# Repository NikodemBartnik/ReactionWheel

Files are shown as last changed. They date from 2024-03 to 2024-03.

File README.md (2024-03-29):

# Reaction Wheel by Nikodem Bartnik
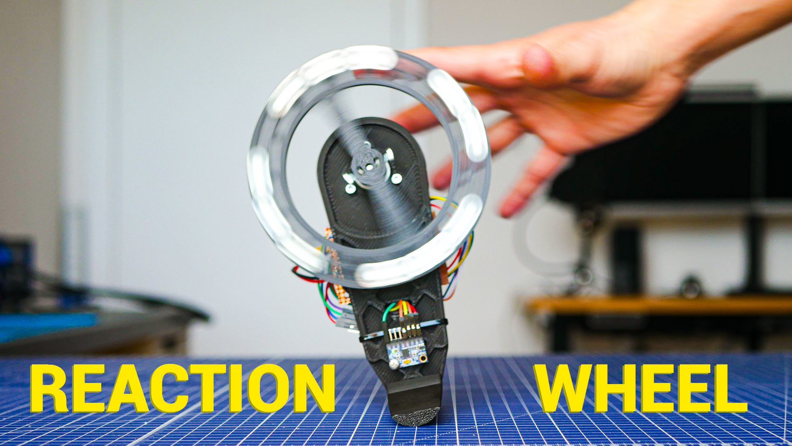
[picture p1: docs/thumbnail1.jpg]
DIY Reaction Wheel by Nikodem Bartnik

At some point in the past, I made a mistake. I embarked on a reaction wheel project, thinking it would be straightforward after watching a few YouTube videos. It turned out to be far from simple. It took me around 4 or 5 attempts to finally complete the project, during which I made numerous mistakes and learned valuable lessons.

Having previously built my own Arduino-based drone, I've come to realize that stability isn't my forte. However, that hasn't dampened my enthusiasm for future projects.

## Overview
The project was initiated in 2019 but was frequently interrupted by other endeavors. There were times when I felt frustrated after days of working on it without making any progress. With this candid introduction, I must caution you that this project isn't the easiest for beginners.

## Parts
Most parts are simply 3D printed. You will also need:
* [Arduino Nano](https://amzn.to/49duqW5)- A small and inexpensive option that can be easily soldered to a protoboard. Opting for a smaller size facilitates stabilizing smaller masses on the reaction wheel.
* [Nidec24H brushless motor](https://s.click.aliexpress.com/e/_DFDXhbX) - This motor is popular for building reaction wheels due to its high torque and integrated driver.
* [MPU6050](https://amzn.to/3Tzr75X) - An affordable and widely used accelerometer and gyroscope. While its data may not be pristine, it gets the job done. Consider upgrading to a higher-quality alternative if necessary, albeit at a higher cost.
* [Protoboard](https://amzn.to/4cDcS8C) - Any size will suffice, and you can always trim it down to fit. It's handy for creating a compact board with all the necessary components attached to the back of your reaction wheel.
* [Bluetooth module](https://amzn.to/3IZgXGY) -  Essential for fine-tuning the PID algorithm.
* Other components: Screws, nuts, LiPo battery, cables.

## Video about the project
Reaction Wheel Video (https://www.youtube.com/watch?v=PdSDhdciSpE)

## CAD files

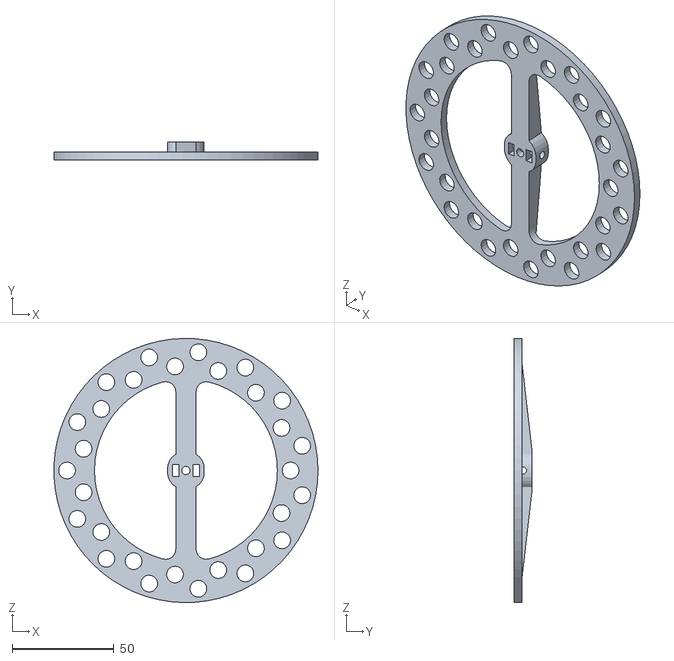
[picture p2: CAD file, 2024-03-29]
CAD/wheel.stl
129.9 x 9.00 x 130.0

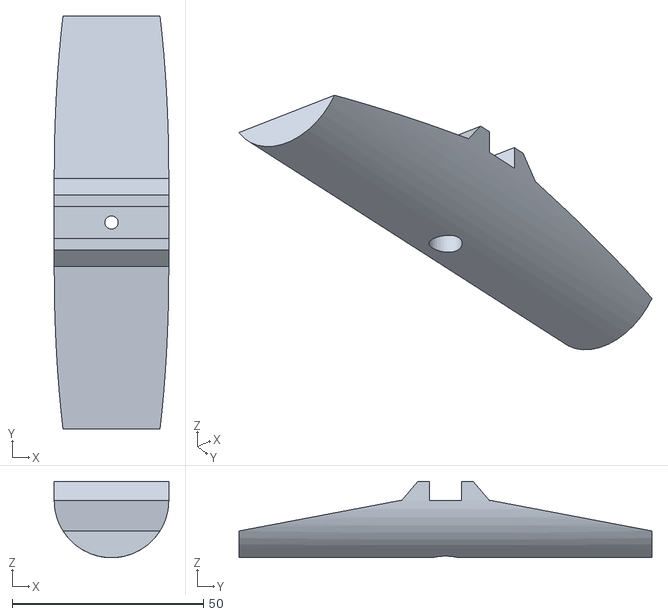
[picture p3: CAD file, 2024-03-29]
CAD/base.stl
30.0 x 108.0 x 20.0

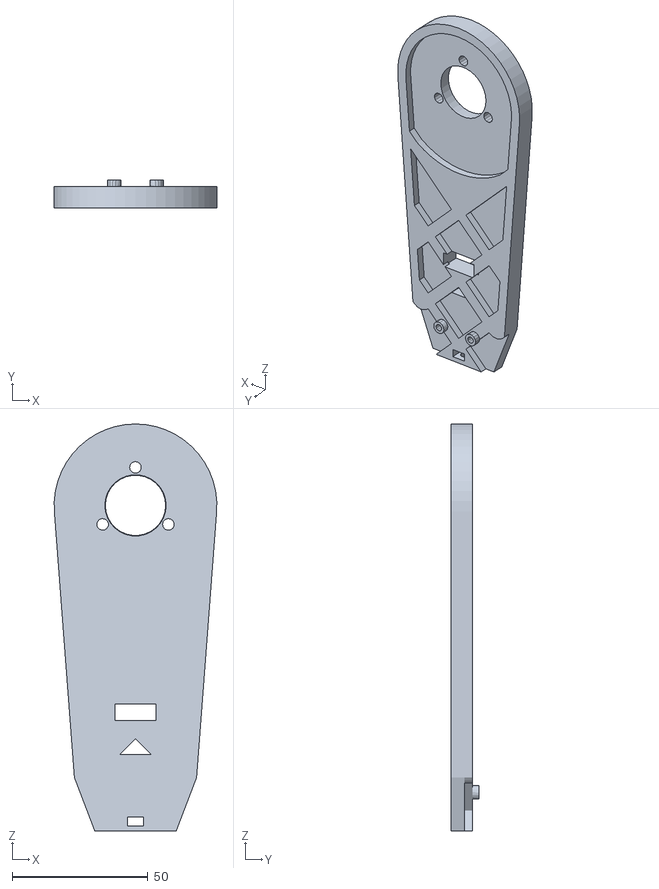
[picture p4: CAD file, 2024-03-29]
CAD/arm.stl
59.9 x 10.5 x 150.0

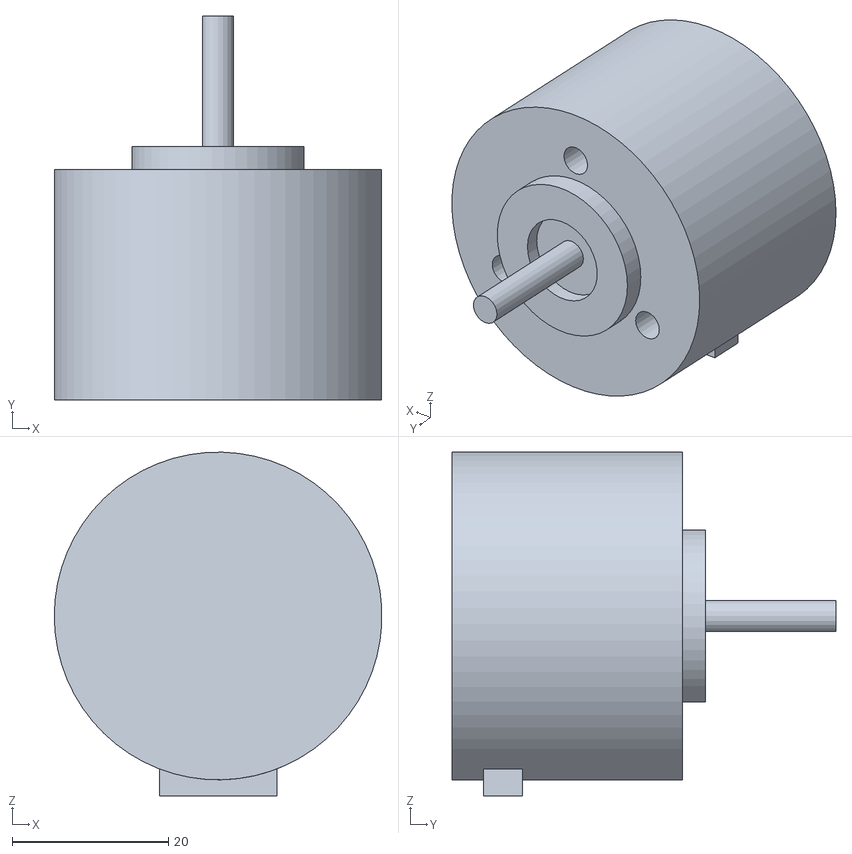
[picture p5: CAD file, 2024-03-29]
CAD/nidec motor.stl
41.9 x 49.1 x 43.9

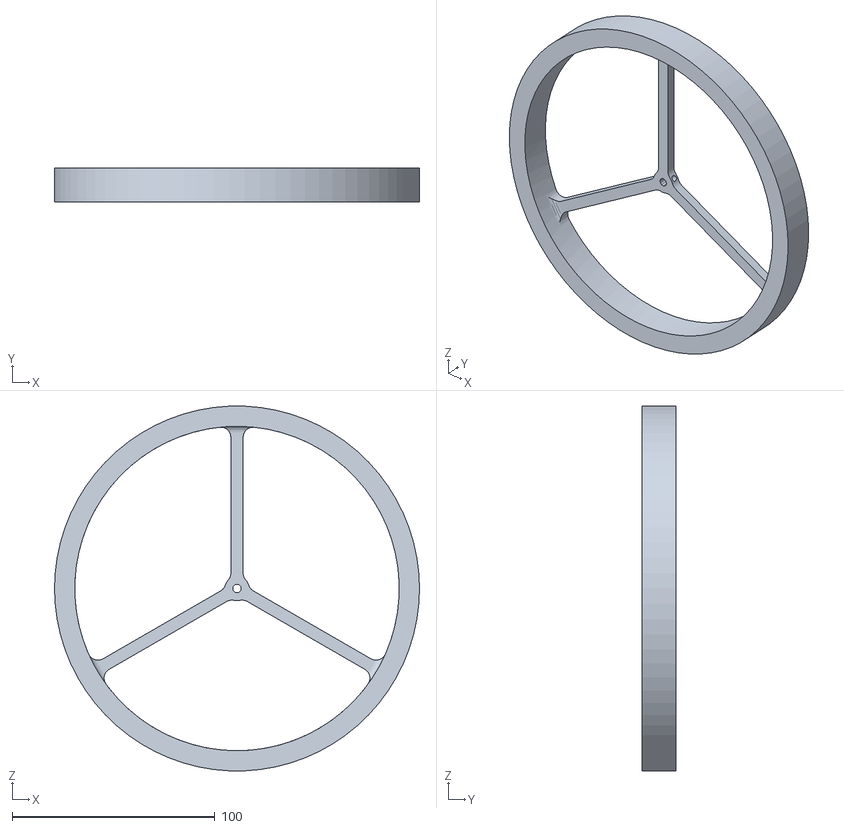
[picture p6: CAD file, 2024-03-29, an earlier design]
CAD/old1/wheel big.stl
180.0 x 17.0 x 179.8

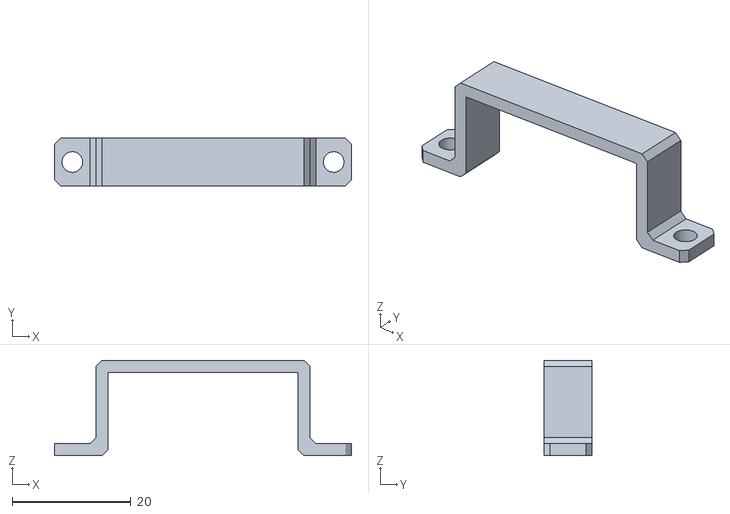
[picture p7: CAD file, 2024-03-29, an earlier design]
CAD/old2/clamp.stl
50.0 x 8.00 x 16.0

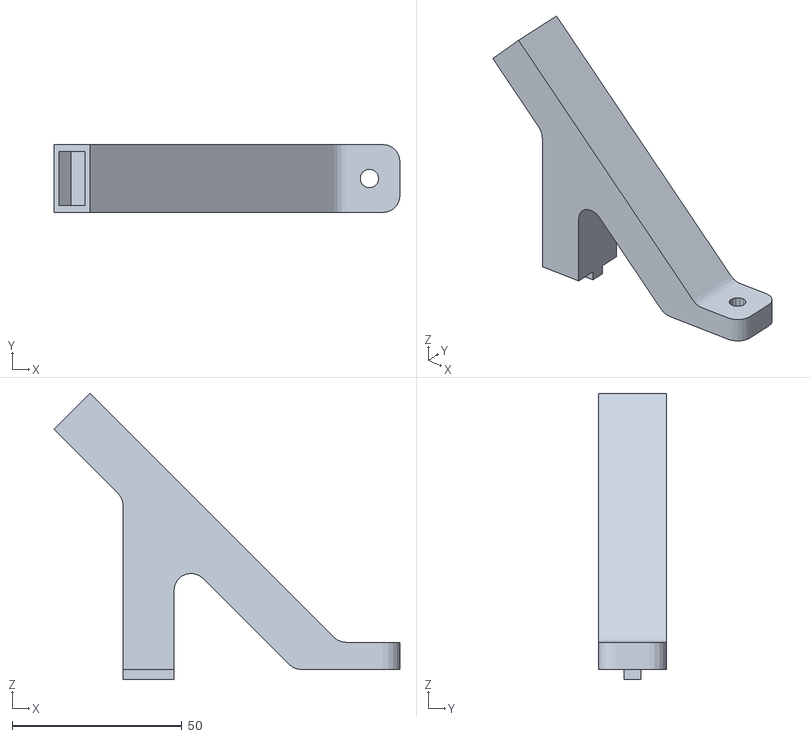
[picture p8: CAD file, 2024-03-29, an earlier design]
CAD/old1/limit.stl
101.9 x 20.0 x 84.3

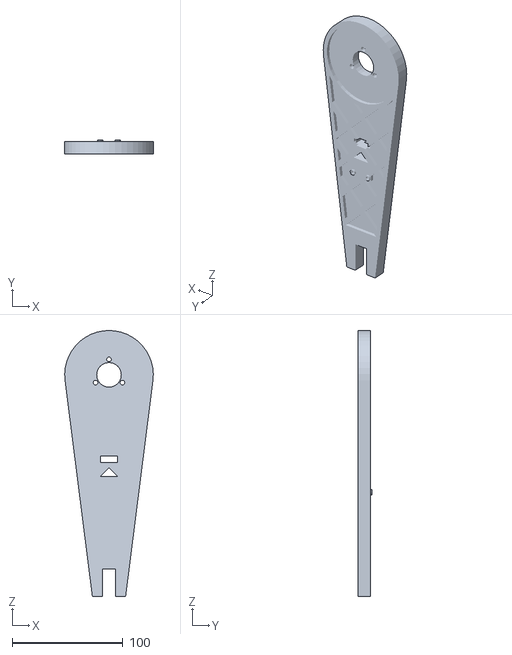
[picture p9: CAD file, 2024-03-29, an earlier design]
CAD/old2/arm.stl
80.0 x 12.5 x 240.0

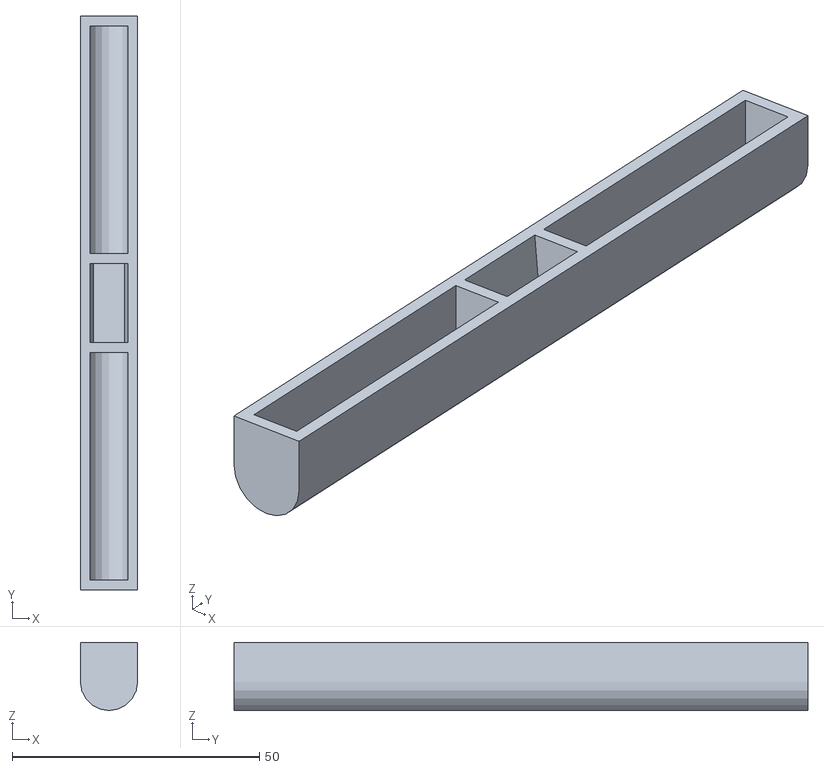
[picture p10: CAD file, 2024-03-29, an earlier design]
CAD/old1/base.stl
11.6 x 116.0 x 13.8

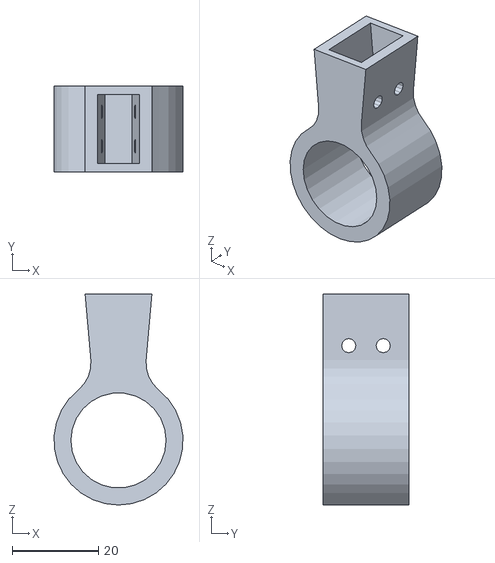
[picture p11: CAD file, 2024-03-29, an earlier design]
CAD/old1/bearing housing.stl
29.9 x 20.0 x 49.0

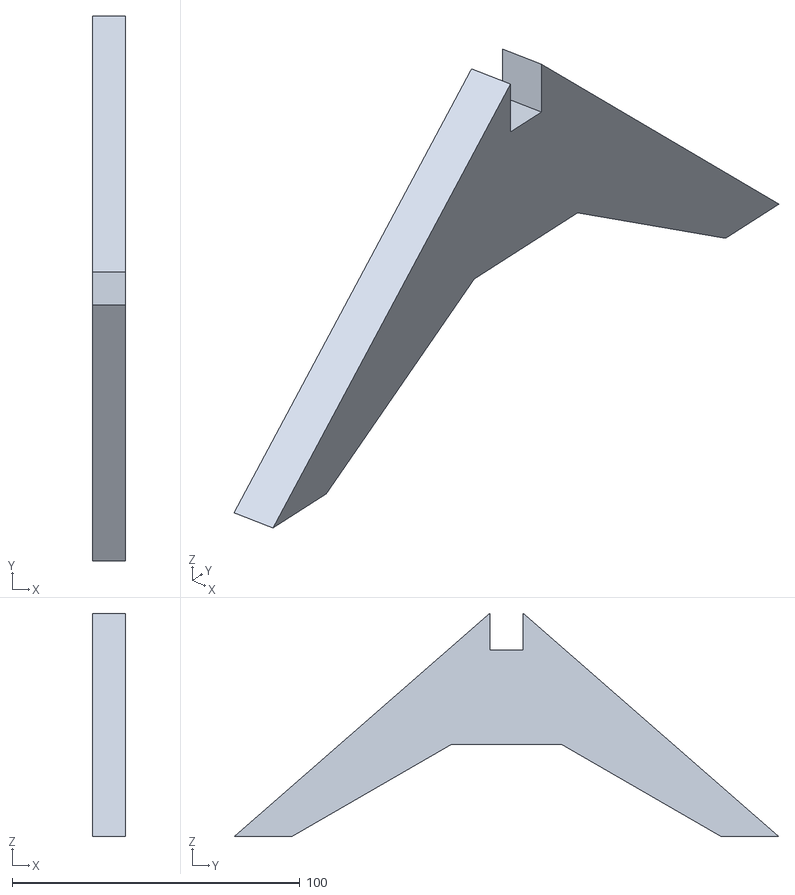
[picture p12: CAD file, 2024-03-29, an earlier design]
CAD/old2/base.stl
11.4 x 189.6 x 77.7

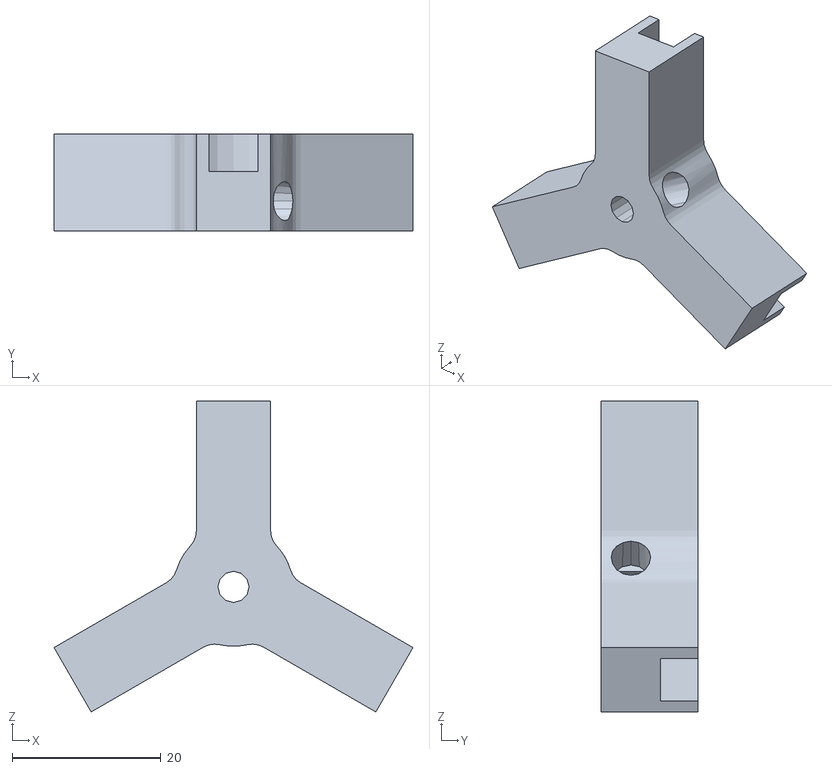
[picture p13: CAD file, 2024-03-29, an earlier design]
CAD/old1/wheel support.stl
48.3 x 13.0 x 41.8

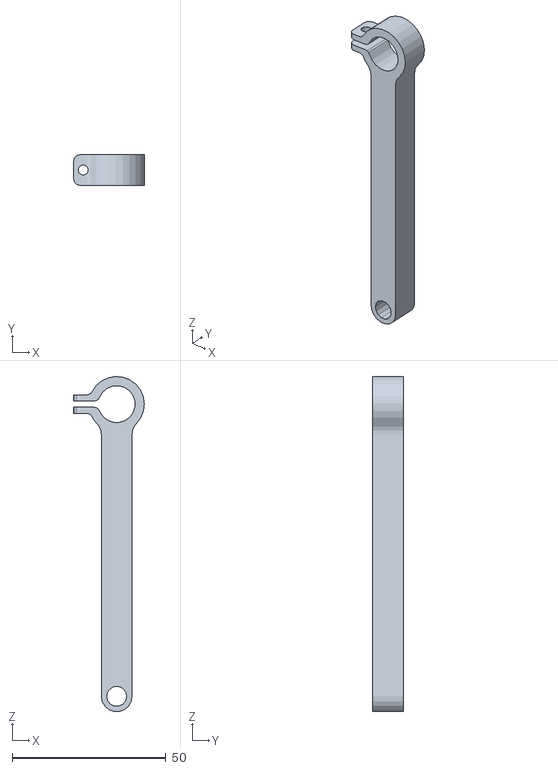
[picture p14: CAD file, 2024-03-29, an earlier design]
CAD/old1/arm1.stl
23.0 x 10.0 x 108.9

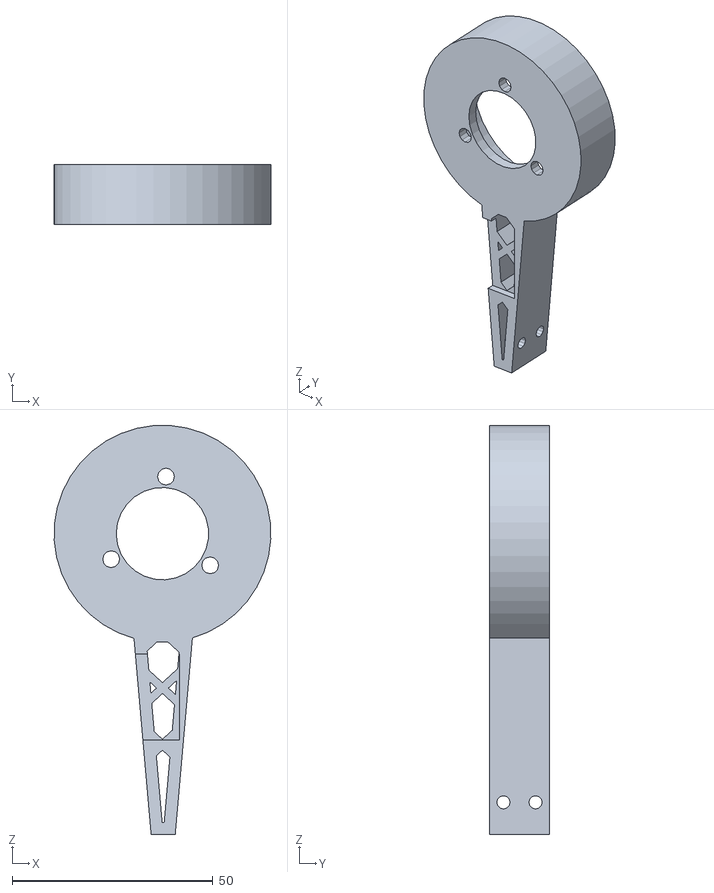
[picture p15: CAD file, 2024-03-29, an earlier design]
CAD/old1/arm2.stl
53.9 x 15.0 x 101.8

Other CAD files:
CAD/old2/wheel.stl
CAD/old1/pin.stl
CAD/old1/base (1).stl
CAD/old1/base (2).stl
CAD/old1/pin2.stl

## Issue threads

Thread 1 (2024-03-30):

Doomed to fail

Markus40, 2024-03-30:
In your video you described your frustrations with the PID-controller. I had a quick look at the code. The main problem is that you have no way of desaturating your balancing wheel. If your design is not perfectly balanced, or you have noise in your sensor, it will only be stable for a limited amount of time.

The centre of gravity will be slightly to the side. At the desired target angle of 0 the balance wheel will need to accelerate constantly to counteract the pull until it reaches maximum speed and your model falls.

You need to change your target angle to desaturate your balance wheel. This can be done with a second PID-controller (I suspect a PI-controller or I-controller would suffice) that changes the target angle with the wheel speed as input.

In the video at 01:48 you show a [project](https://www.youtube.com/watch?v=WObG2LoSEwQ) from which I suspect you got a lot of code ideas. The I-controller is implemented here:
`#reduce continuous rotation
targetAngle -= ANGLE_FIXRATE_2 * wheelAV * timeDelta`.
The parameter `ANGLE_FIXRATE_2` is the I term. This allows this balancing robot to change its centre of gravity so much.

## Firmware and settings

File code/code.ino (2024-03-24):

/*
Author: Nikodem Bartnik
website: https://indystry.cc, https://nikodembartnik.pl
email: nikodem@indystry.cc
inspired by: https://github.com/remrc/One-Axis-Reaction-Wheel-Stick
*/

#include <Wire.h>

#define MPU6050 0x68         // Device address
#define accSens 0             // 0 = 2g, 1 = 4g, 2 = 8g, 3 = 16g
#define gyroSens 1            // 0 = 250rad/s, 1 = 500rad/s, 2 1000rad/s, 3 = 2000rad/s
#define Gyro_amount 0.996     // percent of gyro in complementary filter
#define MOTOR 9
#define DIR 4

// float Kp = 75;
// float Ki = 2;
// float Kd = 3;

float Kp = 100;
float Ki = 4.8;
float Kd = 9.7;
float loop_time = 10;

//IMU offset values
int16_t  AcX_offset = -750;
int16_t  AcY_offset = 360;
int16_t  AcZ_offset = 0;
int16_t  GyZ_offset = 0;
int32_t  GyZ_offset_sum = 0;
int16_t AcX, AcY, AcZ, GyZ, gyroZ;

float target_angle = 0;
float current_angle;
float acc_angle;
bool vertical = false;
float errorSum = 0;
float lastError = 0;
long current_time, previous_time = 0;
uint8_t i2cData[14];

void setup() {
  delay(1000);
  angle_setup();
  Serial.begin(9600);

  pinMode(MOTOR, OUTPUT);
  pinMode(DIR, OUTPUT);
  analogWrite(MOTOR, 255);
}

void loop() {
  current_time = millis();
  checkBluetooth();
  if (current_time - previous_time >= loop_time) {
    angle_calc();
    if (vertical) {
      float error = current_angle - target_angle;
      errorSum += error;
      errorSum = constrain(errorSum, -80, 80);
      float derivative = (error - lastError) / (loop_time/1000);
      int motor_pwm = constrain(Kp * error + Ki * errorSum + Kd * derivative, -255, 255);

      if (motor_pwm > 0) {
        digitalWrite(DIR, LOW);
      } else {
        digitalWrite(DIR, HIGH);
      }
      analogWrite(MOTOR, 1-abs(motor_pwm));

      // if (current_angle > 0) {
      //   target_angle -= 0.003;
      // } else {
      //   target_angle += 0.00;
      // }
      // target_angle = constrain(target_angle, -1, 1);

      lastError = error;
      previous_time = current_time;
    } else {
      target_angle = 0;
      analogWrite(MOTOR, 255);
      errorSum = 0;
    }
  }
}

void writeTo(byte device, byte address, byte value) {
  Wire.beginTransmission(device);
  Wire.write(address);
  Wire.write(value);
  Wire.endTransmission(true);
}

void angle_setup() {
  Wire.begin();
  delay(100);
  writeTo(MPU6050, 0x6B, 0);
  writeTo(MPU6050, 0x1C, accSens << 3); // Specifying output scaling of accelerometer
  writeTo(MPU6050, 0x1B, gyroSens << 3); // Specifying output scaling of gyroscope
  delay(100);

  for (int i = 0; i < 1024; i++) {
    angle_calc();
    GyZ_offset_sum += GyZ;
    delay(5);
  }
  GyZ_offset = GyZ_offset_sum >> 10;
}

void angle_calc() {
  Wire.beginTransmission(MPU6050);
  Wire.write(0x3B);
  Wire.endTransmission(false);
  Wire.requestFrom(MPU6050, 4, true);
  AcX = Wire.read() << 8 | Wire.read();
  AcY = Wire.read() << 8 | Wire.read();

  Wire.beginTransmission(MPU6050);
  Wire.write(0x47);
  Wire.endTransmission(false);
  Wire.requestFrom(MPU6050, 2, true);
  GyZ = Wire.read() << 8 | Wire.read();

  AcX += AcX_offset;
  AcY += AcY_offset;
  AcZ += AcZ_offset;
  GyZ -= GyZ_offset;

  current_angle += GyZ * loop_time / 1000 / 65.536;
  acc_angle = atan2(AcY, -AcX) * 57.2958;
  current_angle = current_angle * Gyro_amount + acc_angle * (1.0 - Gyro_amount);

  if (abs(current_angle) > 12) vertical = false;
  if (abs(current_angle) < 0.3) vertical = true;
}

void checkBluetooth(){
while (Serial.available()) {
    int data = Serial.read();
    if (data == 70) {
      //Forward
      Kp += 1;
    }else if(data == 66) {
      //Backward
      Kp -= 1;
    }else if(data == 76){
      Ki -= 0.1;
    }else if(data == 82){
      Ki += 0.1;
    }else if(data == 88){
      Kd += 0.1;
    }else if(data == 89){
      Kd -= 0.1;
    }

    Serial.print("KP: ");
    Serial.print(Kp);
    Serial.print(" KI: ");
    Serial.print(Ki);
    Serial.print(" KD: ");
    Serial.println(Kd);
}
}
